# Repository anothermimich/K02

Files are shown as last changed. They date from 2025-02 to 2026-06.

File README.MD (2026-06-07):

<p float="center">
   
   
   
</p>

**Less, but better.** - Dieter Rams

After seeing the [Ferris Sweep](https://github.com/davidphilipbarr/Sweep) for the first time I've fallen in love, but as a designer I cannot accept things the way they are. So I've done some experimentation with it. I changed the overall form of the board so it can be a little bit more compact and be a canvas for expression in the matter of case design.

This is a parcial redesign of the [Ferris Sweep 2 half-swept](https://github.com/davidphilipbarr/Sweep). In other words this is a:

- 34 keys.
- Diodeless.
- Low profile.
- Non-hotswap.
- Reversible PCB.
- Column staggered.
- [Tenting puck](https://splitkb.com/products/tenting-puck) compatible.
- Wireless and wired capable.
- Choc MBK spaced (17,5mm x 16,5mm).
- Cheaper than the [cheapino](https://github.com/tompi/cheapino) (at the time of the build).

### What have been done:

- Change PCB overall form.
- Add support screw holes.
- Create an [assembly manual](/other/manuals/k02-assembly-manual.pdf).
- Add teardrop on solder joints.
- Reposition of the reset and power switch.
- Create an alternative version with `USB-C` instead of `TRRS`.
- Add commissioned art by the brazilian artist [Aline Dal Pont](https://www.instagram.com/manifesto.efemero/).
- Remove all the informative silk graphics for a better looking board.

### What I may do<sup>1</sup>:

- Rotate the main switches.
- Change the `USB-C` location.
- Add open hardware logo on silk.
- Make it compatible with choc V2 switches.
- Design some _minimalist_ and _low profile_ cases.

> <sup>1</sup> The main reason for not doing this at the moment is the lack of financial motivation. As I have to pay for every prototype and take time off to do the development and iterations I have to be mindful of the tasks I take. If you want to help [buy me a coffee](https://ko-fi.com/luimmich) or [contact me](https://www.reddit.com/user/kynikoi_/) :)

## Silk art

I commissioned the work of the brazilian artist [Aline Dal Pont](https://www.instagram.com/manifesto.efemero/) for this board. You can use it as it is (with the credits) for non-commercial ends. You cannot use the work outside of this board, modify it in any way or use it commercially without the express autorization of the artist.

<p float="center">
   
   
</p>

## Versions

The `rev. 01` contains 2 versions, one with `TRRS` and one with `USB-C` connecting the halves<sup>2</sup>.

The `rev. 02` are under development. It will introduce an choc V1 and V2 hybrid version of the `USB-C` version.

> <sup>2</sup> The `TRRS` connector are objectively worse than the `USB-C` for this use case, due to it introducing a risk of short in the case that the halves are unpluged with the board powered on. On the other side, the `USB-C` if not wired correctly may introduce a [risk of being connected directly to a power supply](https://docs.qmk.fm/features/split_keyboard) by mistake. I've done the bare minimum to prevent it, I wired the `GND` and `VCC` trying to follow the USB protocol. Another problem with the `USB-C` is that this implementation doesn't follow the USB protocol, it just hijack some of the data pins.

The [gerber files are in the release section.](https://github.com/anothermimich/K02/releases)
The detailed list of materials for each version are inside of the respective folder.

## Assembly

As the pcb doesn't have any information guiding the assembly, I have done an [assembly manual with visual instructions](/other/manuals/k02-assembly-manual.pdf).

<a href="/other/manuals/k02-assembly-manual.pdf" float="center">
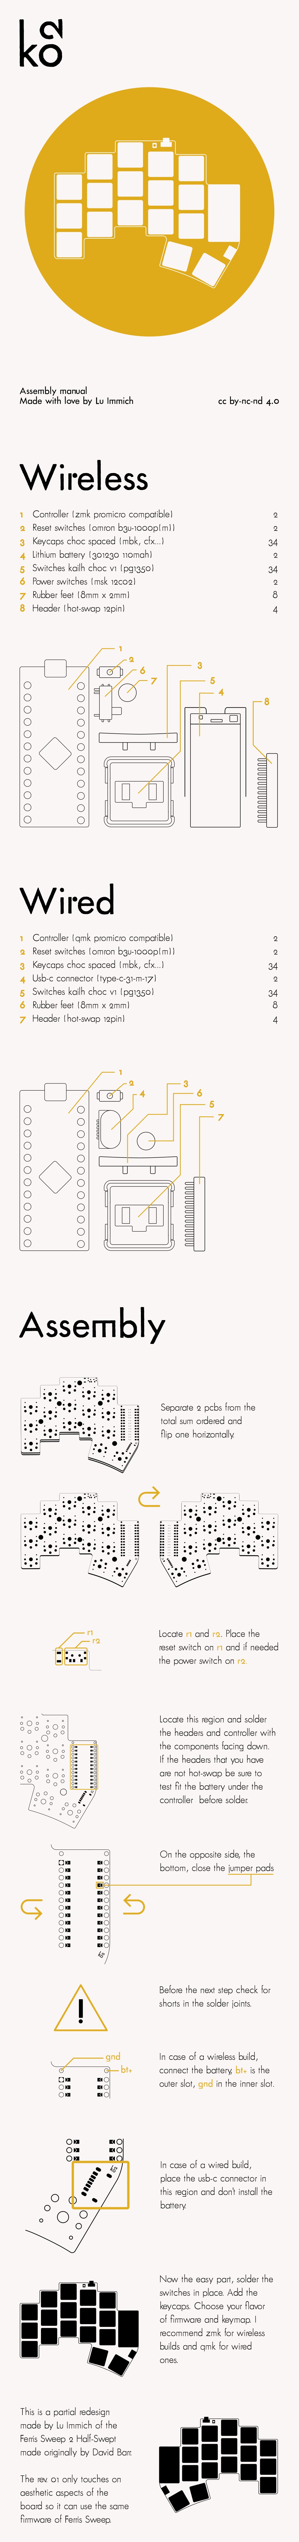
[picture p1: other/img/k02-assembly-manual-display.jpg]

</a>

## Keymap

As the `rev. 01` maintain the pin out of the [Ferris Sweep](https://github.com/davidphilipbarr/Sweep) you can use any compatible keymap/firmware.

Currenty I'm using the above [zmk](https://zmk.dev/) keymap, you can replicate it with [this files](https://github.com/anothermimich/zmk-config-k02).

<a href="https://github.com/anothermimich/zmk-config-k02" float="center">

</a>

> I've tried to use the [Miryoku ZMK](https://github.com/manna-harbour/miryoku_zmk) keymap made by [Manna Harbour](https://github.com/manna-harbour), but I was not able to adapt it to my needs. If you want to see my initial setup take a look at the [compiled firmware](/other/old%20miryoku%20keymaps/) or the source [github workflow](https://github.com/anothermimich/miryoku_zmk/blob/master/.github/workflows/workflow-build-k02.yml), [custom_config.h](https://github.com/anothermimich/miryoku_zmk/blob/master/miryoku/custom_config.h), [cradio_left.conf](https://github.com/anothermimich/miryoku_zmk/blob/master/config/cradio_left.conf) and [cradio_right.conf](https://github.com/anothermimich/miryoku_zmk/blob/master/config/cradio_right.conf) files.

## Disclaimer

The files in this repo may contain problems, use them at your own risk.

For the type nerds _(like me)_, the text on the PCB and logo are [FuturaRenner](https://www.fontsquirrel.com/fonts/futura-renner) aka [Formera](https://github.com/noirblancrouge/Formera).

The team behind the design of the incredible [Ferris Sweep](https://github.com/davidphilipbarr/Sweep) are: [Pierre Chevalier](https://github.com/pierrechevalier83), [David Barr](https://github.com/davidphilipbarr), [Ibnu Daru Aji](https://github.com/ibnuda/), [Duccio](https://github.com/duckyb). Without their work this parcial redesign would not be possible.

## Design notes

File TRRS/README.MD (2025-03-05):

# Necessary Components

| Quantity | What |
| --- | --- |
| 34 | Switches ([Kailh PG1350/choc V1](https://cdn-shop.adafruit.com/product-files/5113/CHOC+keyswitch_Kailh-CPG135001D01_C400229.pdf)) |
| 34 | Keycaps choc v1 spaced ([MBK](https://fkcaps.com/keycaps/mbk) are the ideal size) |
| 2 | Reset switches (Omron [B3U-1000P(M)](https://omronfs.omron.com/en_US/ecb/products/pdf/en-b3u.pdf)) |
| 4 | Header ([12pin](https://github.com/joric/nrfmicro/wiki/Sockets)) |
| ? | Rubber feet (8mm x 2mm) |

## Wireless

| What | Quantity |
| ---- | --- |
| 2 | Controller ([nrf52840](https://github.com/joric/nrfmicro/wiki/Alternatives)) |
| 2 | Power switches (MSK 12C02) |
| 2 | Lithium battery ([301230](https://github.com/joric/nrfmicro/wiki/Batteries)) |

## Wired

| What | Quantity |
| ---- | --- |
| 2 | Controller ([QMK pro micro compatible mcu](https://github.com/qmk/qmk_firmware/blob/master/docs/compatible_microcontrollers.md)) |
| 1 | USB Cable (depends on the micro-controller used) |
| 2 | TRRS jack (PJ-320A) |
| 1 | TRRS to TRRS cable |

# PCB

<p float="center">
   
   
</p>

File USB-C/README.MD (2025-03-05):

# Production files

The [gerber files can be found in the release section.](https://github.com/anothermimich/K02/releases)

# Necessary Components

| Quantity | What |
| --- | --- |
| 34 | Switches ([Kailh PG1350/choc V1](https://cdn-shop.adafruit.com/product-files/5113/CHOC+keyswitch_Kailh-CPG135001D01_C400229.pdf)) |
| 34 | Keycaps choc v1 spaced ([MBK](https://fkcaps.com/keycaps/mbk) are the ideal size) |
| 2 | Reset switches (Omron [B3U-1000P(M)](https://omronfs.omron.com/en_US/ecb/products/pdf/en-b3u.pdf)) |
| 4 | Header ([12pin](https://github.com/joric/nrfmicro/wiki/Sockets)) |
| 10 | Rubber feet (8mm x 2mm) |

## Wireless

| What | Quantity |
| ---- | --- |
| 2 | Controller ([nrf52840](https://github.com/joric/nrfmicro/wiki/Alternatives)) |
| 2 | Power switches (MSK 12C02) |
| 2 | Lithium battery ([301230](https://github.com/joric/nrfmicro/wiki/Batteries)) |

## Wired

| What | Quantity |
| ---- | --- |
| 2 | Controller ([QMK pro micro compatible mcu](https://github.com/qmk/qmk_firmware/blob/master/docs/compatible_microcontrollers.md)) |
| 1 | USB Cable (depends on the micro-controller used) |
| 2 | USB-C connector ([TYPE-C-31-M-17](https://www.lcsc.com/datasheet/lcsc_datasheet_2410010030_Korean-Hroparts-Elec-TYPE-C-31-M-17_C283540.pdf)) |
| 1 | USB-C to USB-C cable |

# Assembly manual

Check the [assembly manual](https://github.com/anothermimich/K02/blob/main/other/manuals/k02-assembly-manual.pdf) for a detailed guide on the process of putting this board together.

# PCB

<p float="center">
   
   
</p>

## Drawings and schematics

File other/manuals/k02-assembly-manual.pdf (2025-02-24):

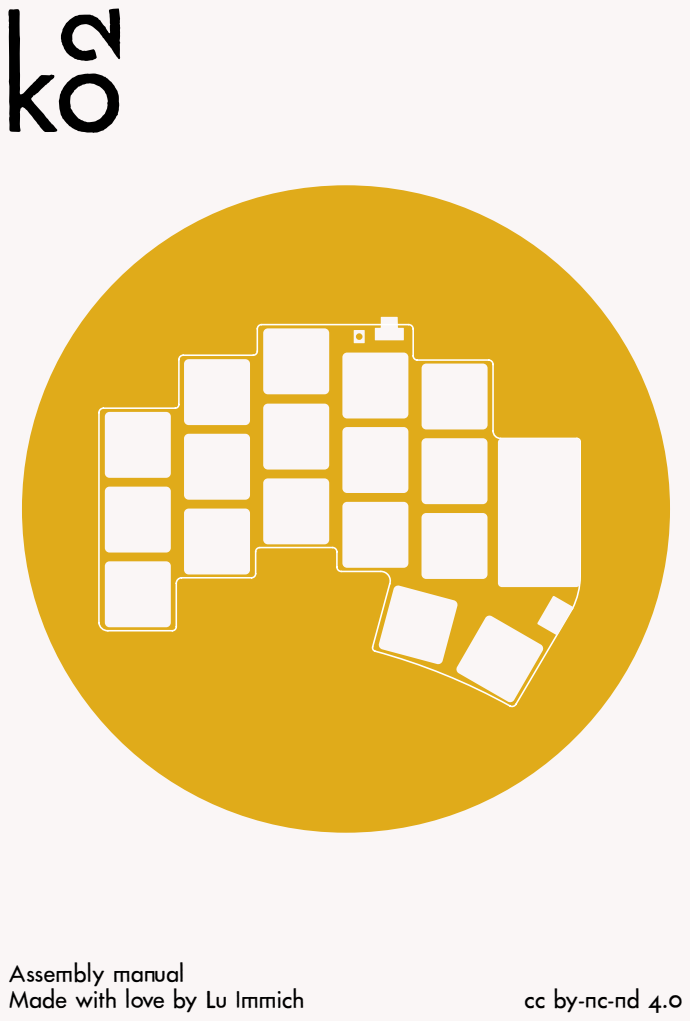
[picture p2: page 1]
Assembly manual; Made with love by Lu Immich

# Wireless

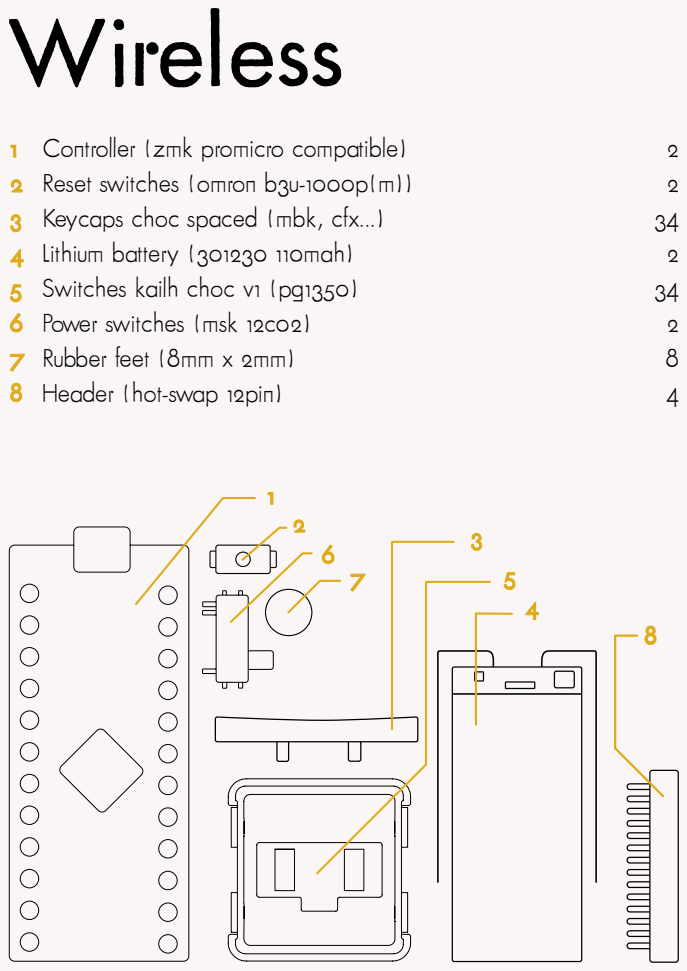
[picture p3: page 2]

Controller (zmk promicro compatible)
Reset switches (omron b3u-1000p(m))
Keycaps choc spaced (mbk, cfx...)
Lithium battery (301230 110mah)
Switches kailh choc v1 (pg1350)
Power switches (msk 12c02)
Rubber feet (8mm x 2mm)
Header (hot-swap 12pin)

# Wired

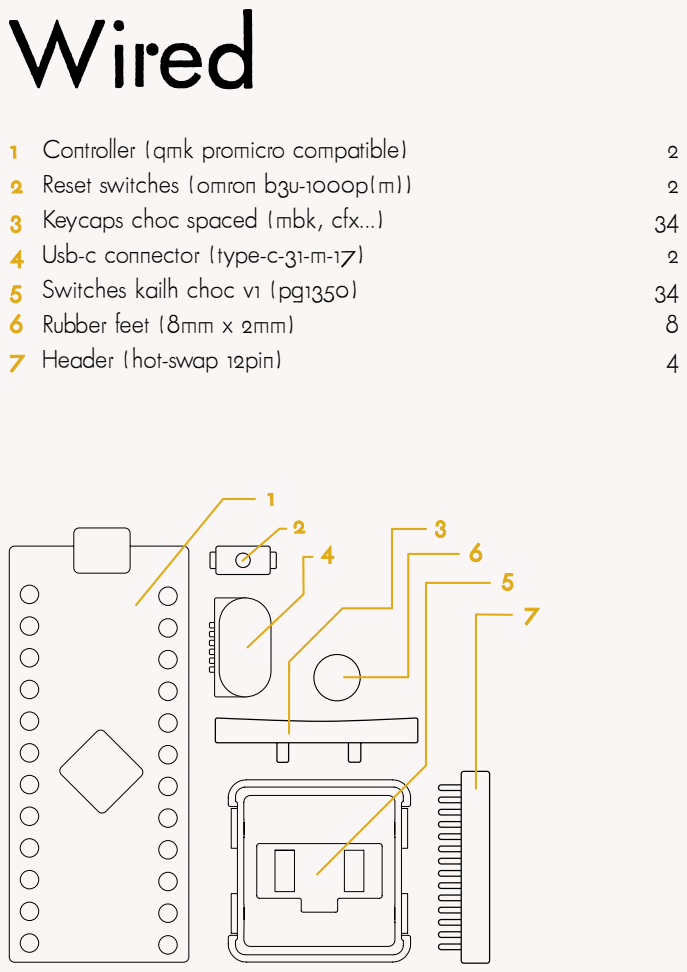
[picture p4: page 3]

Controller (qmk promicro compatible)
Reset switches (omron b3u-1000p(m))
Keycaps choc spaced (mbk, cfx...)
Usb-c connector (type-c-31-m-17)
Switches kailh choc v1 (pg1350)
Rubber feet (8mm x 2mm)
Header (hot-swap 12pin)

# Assembly

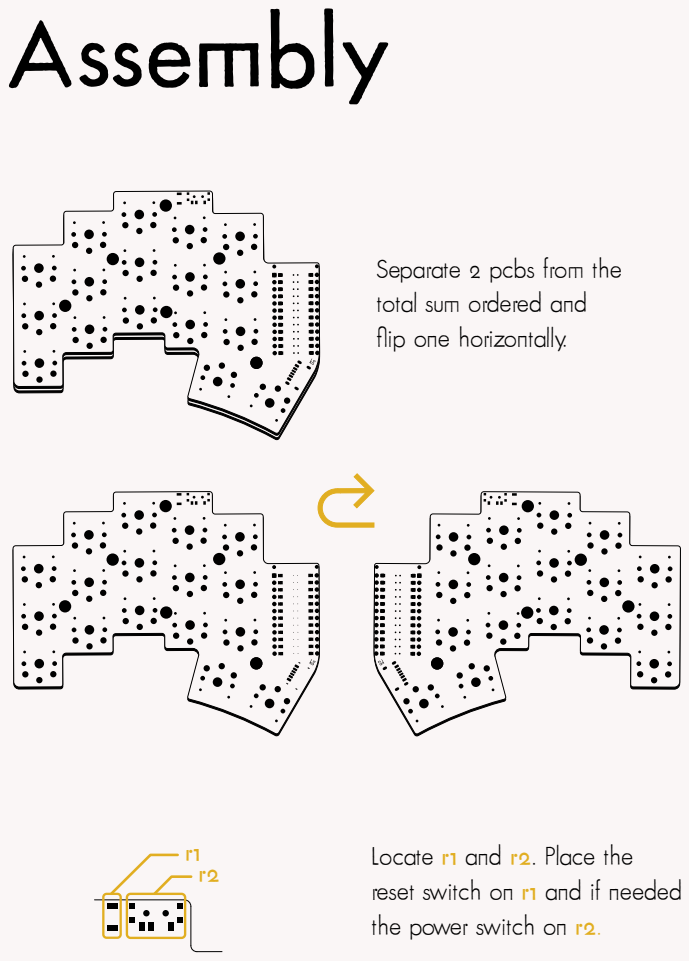
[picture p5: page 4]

Separate 2 pcbs from the
total sum ordered and
flip one horizontally.

Locate r1 and r2. Place the
reset switch on r1 and if needed
the power switch on r2.

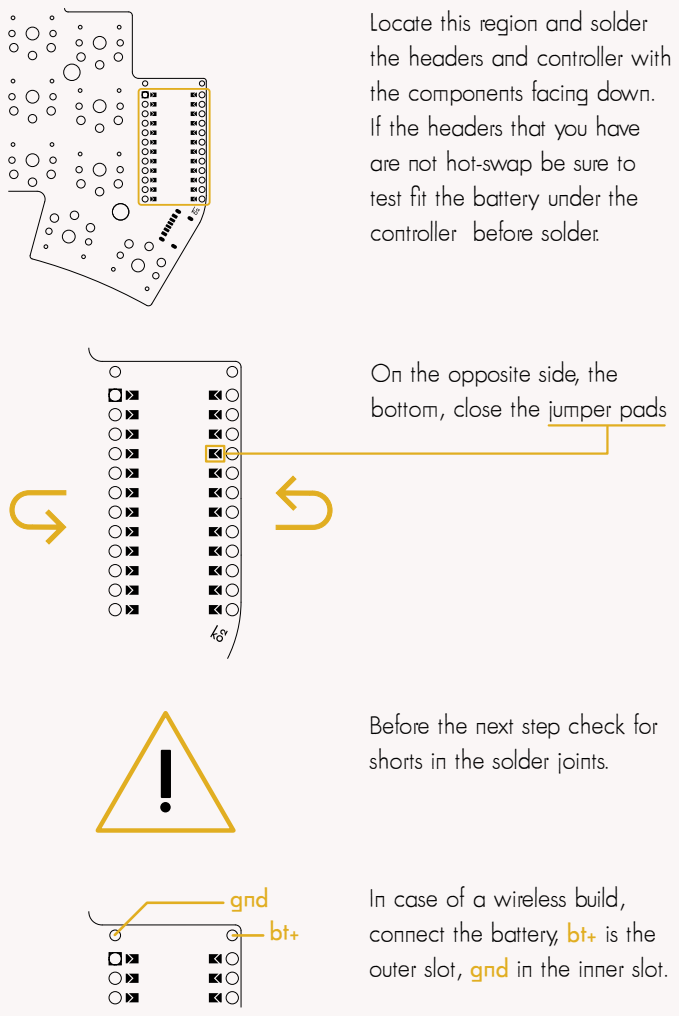
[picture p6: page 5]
gnd

Locate this region and solder
the headers and controller with
the components facing down.
If the headers that you have
are not hot-swap be sure to
test fit the battery under the
controller before solder.

On the opposite side, the
bottom, close the jumper pads

Before the next step check for
shorts in the solder joints.

In case of a wireless build,
connect the battery, bt+ is the
outer slot, gnd in the inner slot.

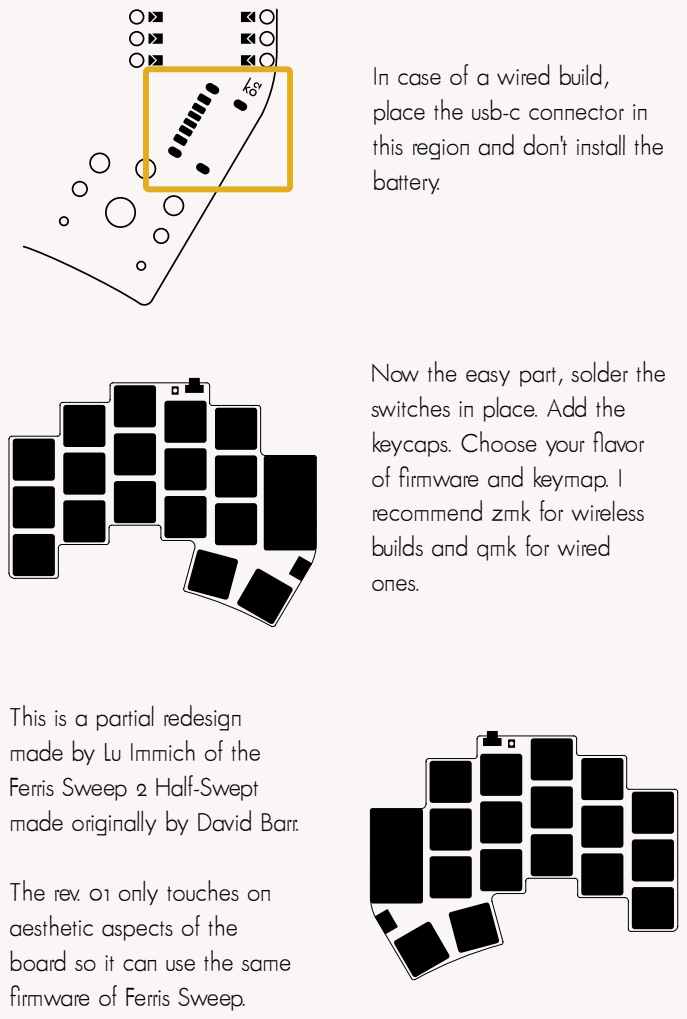
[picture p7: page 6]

In case of a wired build,
place the usb-c connector in
this region and don't install the
battery.

Now the easy part, solder the
switches in place. Add the
keycaps. Choose your flavor
of firmware and keymap. I
recommend zmk for wireless
builds and qmk for wired
ones.

This is a partial redesign
made by Lu Immich of the
Ferris Sweep 2 Half-Swept
made originally by David Barr.

The rev. 01 only touches on
aesthetic aspects of the
board so it can use the same
firmware of Ferris Sweep.

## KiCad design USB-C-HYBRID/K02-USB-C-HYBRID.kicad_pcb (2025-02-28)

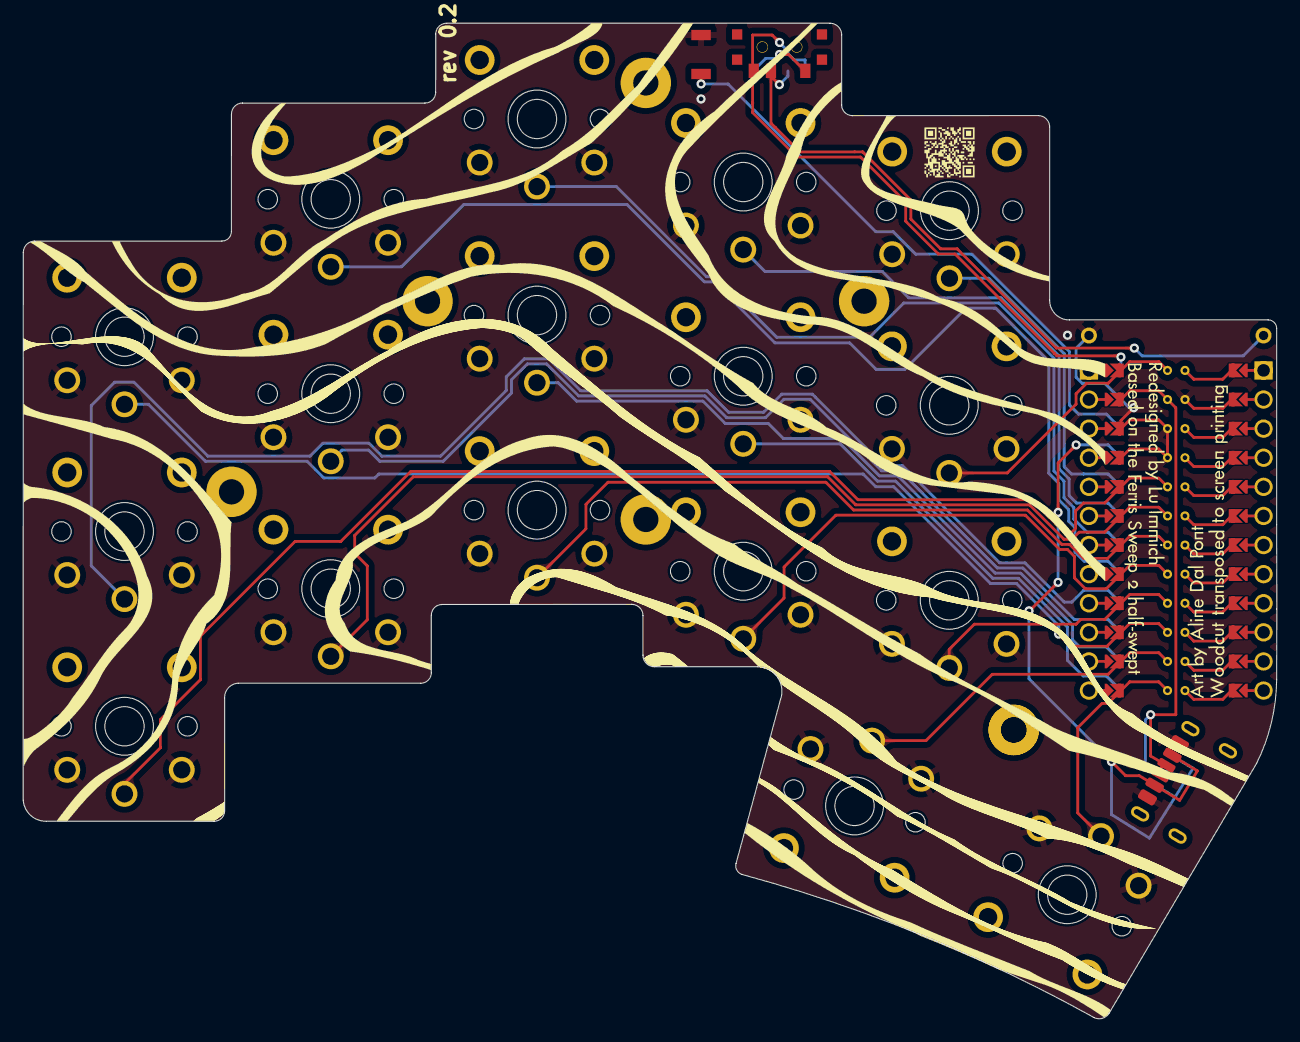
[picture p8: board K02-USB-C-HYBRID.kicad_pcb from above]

Board: 2 copper layers, 109.4 x 86.9 mm, 22 parts (0 on the bottom side), 21 nets.

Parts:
B+: MountingHole_Pad; 1pin_conn
B-: MountingHole_Pad; 1pin_conn
POWER SW: SW_SPDT; SPDT_C128955
RSW2: SW_Push; Tactile-Switch_SMT
SW1, SW2, SW3, SW4, SW5, SW6, SW7, SW8, SW9, SW10, SW11, SW12, SW13, SW14, SW15, SW16, SW17: SW_Push; choc_v1_v2_rev_inv
U1: ProMicro-kbd; ProMicro_jumpers_facedown

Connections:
BT+_r: B+.1, POWER SW.2
Switch1: SW1.1, U1.10
Switch2: SW2.1, U1.17
Switch3: SW3.1, U1.18
Switch4: SW4.1, U1.19
Switch5: SW5.1, U1.20
Switch6: SW6.1, U1.16
Switch7: SW7.1, U1.15
Switch8: SW8.1, U1.14
Switch9: SW9.1, U1.13
Switch10: SW10.1, U1.1
Switch11: SW11.1, U1.5
Switch12: SW12.1, U1.6
Switch13: SW13.1, U1.7
Switch14: SW14.1, U1.8
Switch15: SW15.1, U1.9
Switch16: SW16.1, U1.11
Switch17: SW17.1, U1.12
gnd: B-.1, RSW2.1, RSW2.2, SW1.2, SW2.2, SW3.2, SW4.2, SW5.2, SW6.2, SW7.2, SW8.2, SW9.2, SW10.2, SW11.2, SW12.2, SW13.2, SW14.2, SW15.2, SW16.2, SW17.2, U1.3, U1.4, U1.23
raw: POWER SW.3, U1.24
reset: RSW2.1, RSW2.2, U1.22

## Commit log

2025-01-14 assembly preview
2025-02-24 assembly fix
2025-02-25 footprints reversible
2025-02-25 rev 02 intro
    [K02-USB-C-HYBRID.kicad_pcb, K02-USB-C-HYBRID.kicad_sch]
2025-02-26 almost there
    [K02-USB-C-HYBRID.kicad_pcb]
2025-02-28 test gerber
    [K02-USB-C-HYBRID.kicad_pcb]
2025-03-05 battery link
2025-03-13 rev 02 under development
    [K02-USB-C.kicad_pcb, K02-USB-C.kicad_sch]
2025-03-15 here we go again
    [K02-USB-C.kicad_pcb]
2025-03-28 break the repository
    [K02-USB-C.kicad_pcb, K02-USB-C.kicad_sch]
